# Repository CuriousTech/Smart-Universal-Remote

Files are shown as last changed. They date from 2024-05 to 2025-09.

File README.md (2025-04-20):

# Smart-Universal-Remote  
Smart Universal Remote using one of these:  
[Waveshare ESP32-S3-Touch-LCD-1.28](https://www.waveshare.com/wiki/ESP32-S3-Touch-LCD-1.28)  
[Waveshare ESP32-S3-Touch-LCD-1.69](https://www.waveshare.com/wiki/ESP32-S3-Touch-LCD-1.69)  
[WaveShare-ESP32-S3-Touch-LCD-2.8](https://www.waveshare.com/wiki/ESP32-S3-Touch-LCD-2.8)  
[WaveShare-ESP32-S3-Touch-LCD-2inch](https://www.waveshare.com/wiki/ESP32-S3-Touch-LCD-2)  
  
uremote  
uremote2  
  
This is a tiny smart universal remote with WiFi, IR, capacitive touchscreen, wireless charging (and possibly Bluetooth) all for a very low cost.  
  
Parts list:  
  
[AliExpress ESP32-S3-Touch-1.28](https://www.aliexpress.us/item/3256806026101753.html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) This includes the 12p connector with dupont ends.  
  
[AliExpress ESP32-S3-Touch-1.69](https://www.aliexpress.us/item/3256806781994387.html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)  Or this one. It seems they've fixed the original issue, but I'm not buying another one to test it. [Subreddit thread](https://www.reddit.com/r/esp32/comments/1cxmo5r/esp32s3_169inch_touch_display_features_6axis_imu/)  
  
[AliExpress ESP32-S3-Touch-2.8](https://www.aliexpress.us/item/3256807168316377.html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) My new favorite. Comes with dupont connectors, speakers (not yet implemented). No M2.5 screws, but not hard to find. The wireless charging pad may need to go on the back of the case due to screws.  
  
[eBay:Charger pad](https://www.ebay.com/itm/143351559508?var=442544081497) Select USB-C. These can be bought anywhere.  For the latest model, the charger can be centered. The edges of the pad can be bent because the wrapper is a bit oversized. A USB-C cable or magnetic connector will work as well.  

[eBay:battery](https://www.ebay.com/itm/174781170731?var=473957762104) Select 1.25mm plug. This is probably a decent size. Be careful with the polarity. It was correct on mine. They sell a 1500mAh that's just a little thicker, but I may add a keypad that will use the extra space.   

[TinkerCAD Case Models](https://www.tinkercad.com/things/j1XckJlfVuT-waveshare-esp32-s3-touch-128-remote-case) For editing the 3D print models.  
  
[New IRIO board on OSHPark](https://oshpark.com/shared_projects/KRJOFbjO)  I used some double-sided tape to make sure it doesn't touch the other board.  
  
This IR sender/receiver is designed to be built easily using common parts, but Arduino IR modules should be compatible.  If using an NPN transistor for the sender, subtract the vF from 3.3 for R1 plus the IR LED vF. 110 ohms should be good for a MOSFET and 1.2V LED.  
  
The web page. This is used to decode remotes and test output commands. Just hit the decode button and start pushing buttons on a remote. Those values can be entered in the button code[4] array of any buttons created. Mixed remotes on one page, or all the same. Doesn't matter.  
uremoteweb

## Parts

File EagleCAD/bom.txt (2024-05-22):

RC  TSOP394388
R1  110 ohm 0805
R2  1K 0805
C1  1uF 0805
Q3  N-channel SOT-23 (ex. SSM3K333RLF)
LED1 3mm IR LED (had some laying around)

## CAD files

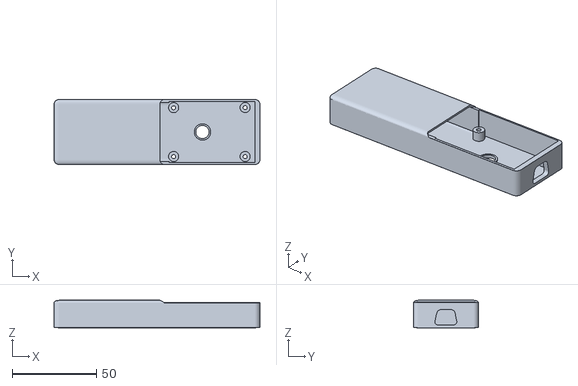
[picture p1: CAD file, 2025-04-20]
3D/WS2inch.stl
122.0 x 38.6 x 16.3

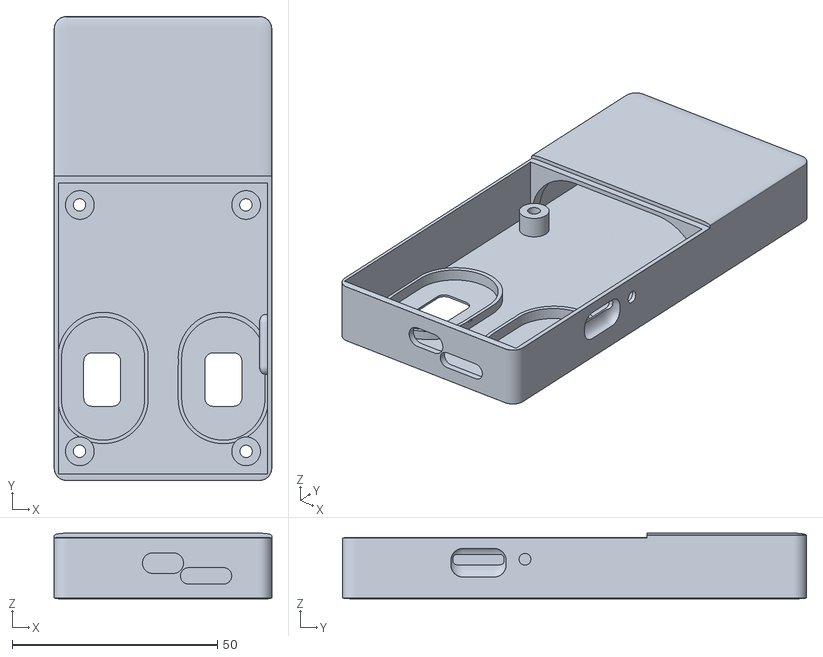
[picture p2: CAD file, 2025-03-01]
3D/WS2.8_Single.stl
53.0 x 113.0 x 16.0

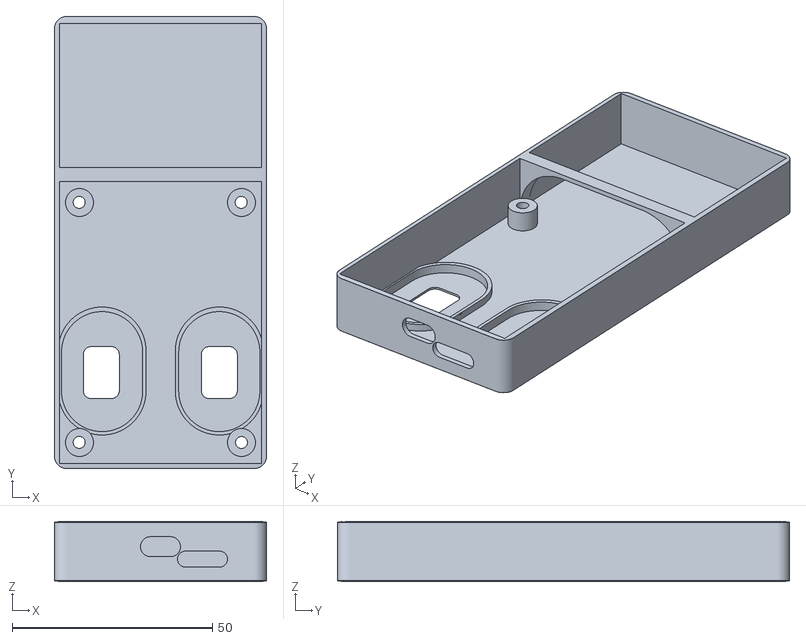
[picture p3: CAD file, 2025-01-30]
3D/WS28Case.stl
53.0 x 113.0 x 15.0

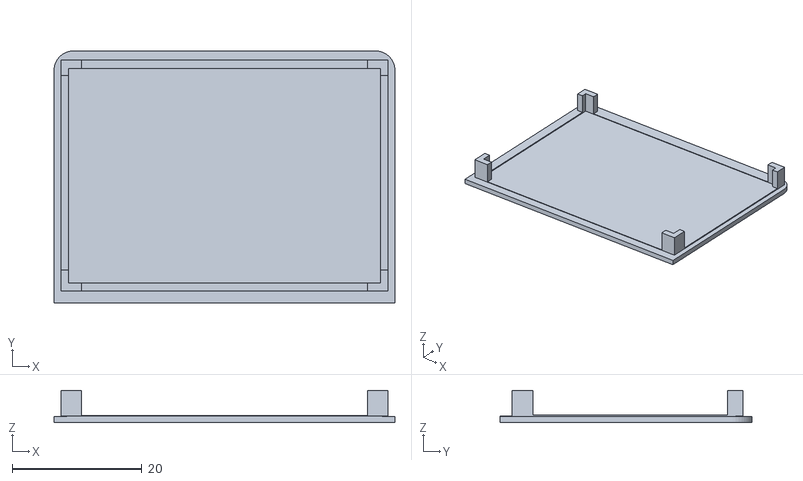
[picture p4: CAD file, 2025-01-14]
3D/WS28Cover.stl
52.5 x 38.8 x 5.00

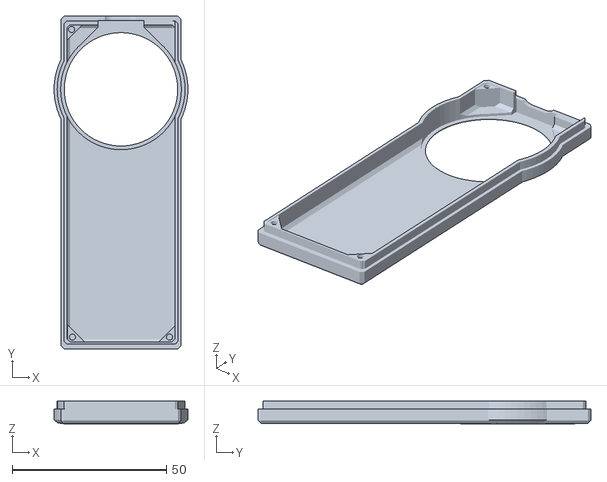
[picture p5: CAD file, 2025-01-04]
3D/URTop.stl
43.5 x 108.0 x 7.36

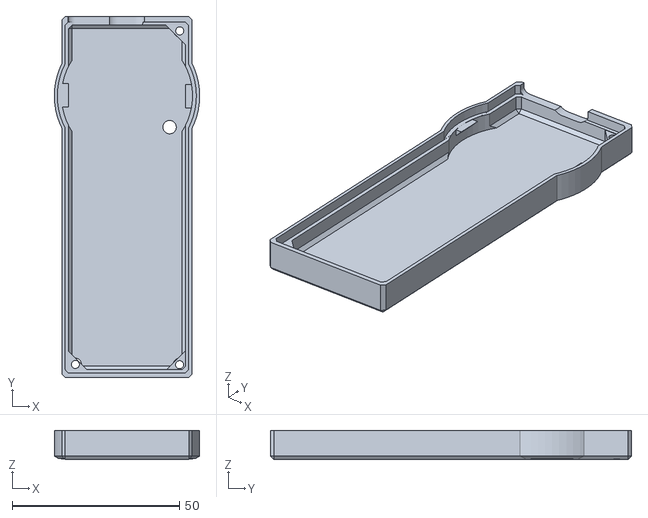
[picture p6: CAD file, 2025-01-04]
3D/URBottom.stl
43.5 x 108.0 x 8.70

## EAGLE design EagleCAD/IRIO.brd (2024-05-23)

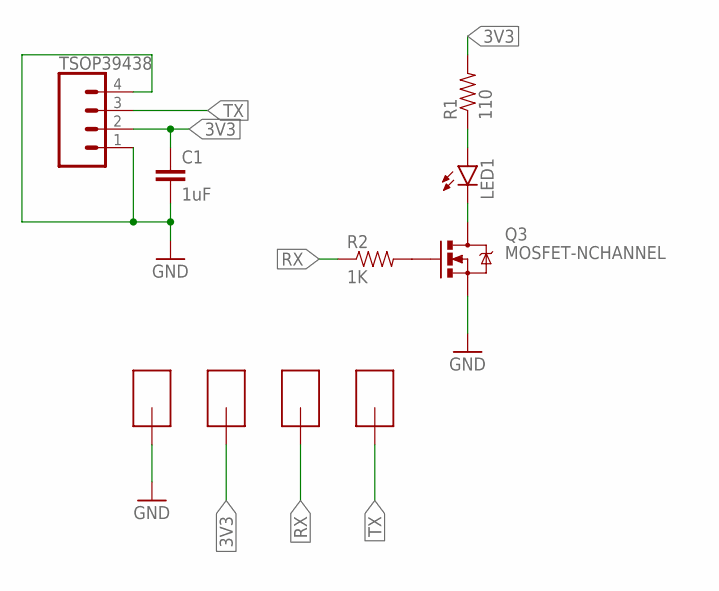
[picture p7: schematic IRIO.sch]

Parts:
C1: 1uF; 0805
LED1: LED5MM
Q3: MOSFET-NCHANNEL; SOT23-3
R1: 110; 0805
R2: 1K; 0805
TSOP39438: CONN_041.27MM; 1X04_1.27MM
U$1, U$2, U$3, U$4: SMD-PAD1SMD-PAD80X32; SMD-PAD6

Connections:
3V3: C1.1, R1.2, TSOP39438.2, U$3.>PAD
GND: C1.2, Q3.2 (S), TSOP39438.1, TSOP39438.4, U$2.>PAD
unnamed: LED1.A, R1.1
unnamed: Q3.1 (G), R2.2
unnamed: LED1.K (C), Q3.3 (D)
RX: R2.1, U$1.>PAD
TX: TSOP39438.3, U$4.>PAD

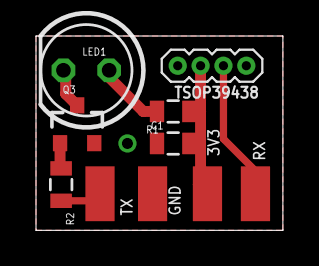
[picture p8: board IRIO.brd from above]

Board: 2 copper layers, 13.7 x 10.8 mm, 10 parts (0 on the bottom side), 7 nets.

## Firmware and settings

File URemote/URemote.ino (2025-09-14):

/**The MIT License (MIT)

Copyright (c) 2024 by Greg Cunningham, CuriousTech

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
THE SOFTWARE IS PROVIDED "AS IS", WITHOUT WARRANTY OF ANY KIND, EXPRESS OR
IMPLIED, INCLUDING BUT NOT LIMITED TO THE WARRANTIES OF MERCHANTABILITY,
FITNESS FOR A PARTICULAR PURPOSE AND NONINFRINGEMENT. IN NO EVENT SHALL THE
AUTHORS OR COPYRIGHT HOLDERS BE LIABLE FOR ANY CLAIM, DAMAGES OR OTHER
LIABILITY, WHETHER IN AN ACTION OF CONTRACT, TORT OR OTHERWISE, ARISING FROM,
OUT OF OR IN CONNECTION WITH THE SOFTWARE OR THE USE OR OTHER DEALINGS IN THE
SOFTWARE.
*/

// Build with Arduino IDE 1.8.57.0
//  ESP32: ( <=2.0.14 or 3.2.0+ ) ESP32S3 Dev Module, QIO, CPU Freq: 80MHz for lowest power (<60mA),
//  Flash: 16MB
//  Partition: 16MB (3MB APP/9.9 FATFS)
// For 1.28" round
//  PSRAM: QSPI PSRAM
//  In TFT_eSPI/User_Setup_Select.h use #include <User_Setups/Setup302_Waveshare_ESP32S3_GC9A01.h>
// For 1.69"
//  PSRAM: OPI PSRAM
//  In TFT_eSPI/User_Setup_Select.h use #include <User_Setups/Setup203_ST7789.h> (custom, included in repo)
// For 2.8"
//  PSRAM: OPI PSRAM
//  In TFT_eSPI/User_Setup_Select.h use #include <User_Setups/Setup303_Waveshare_ESP32S3_ST7789.h> (custom, included in repo)
// For 2"
//  PSRAM: OPI PSRAM
//  In TFT_eSPI/User_Setup_Select.h use #include <User_Setups/Setup304_Waveshare__2inch_ESP32S3_ST7789.h> (custom, included in repo)

#define OTA_ENABLE  //uncomment to enable Arduino IDE Over The Air update code (uses ~4K heap)
#define SERVER_ENABLE // uncomment to enable server and WebSocket
//#define BLE_ENABLE // uncomment for BLE keyboard (uses 510KB (16%) PROGMEN and >100K heap)
#define CLIENT_ENABLE // uncomment for PC WebSocket client
#define IR_ENABLE // uncomment for IR

#include <WiFi.h>
#include "Media.h"
#include "eeMem.h"
#include <time.h>
#include <ESPmDNS.h>
#ifdef OTA_ENABLE
#include <ArduinoOTA.h>
#endif

#ifdef SERVER_ENABLE
#include <ESPAsyncWebServer.h> // https://github.com/mathieucarbou/ESPAsyncWebServer
#include <JsonParse.h> // https://github.com/CuriousTech/ESP-HVAC/tree/master/Libraries/JsonParse
#include "jsonString.h"
#include "pages.h"

#define TZ  "EST5EDT,M3.2.0,M11.1.0"  // https://github.com/nayarsystems/posix_tz_db/blob/master/zones.csv

const char *hostName = "URemote"; // Device and OTA name

tm gLTime;
Media media;

AsyncWebServer server( 80 );
AsyncWebSocket ws("/ws"); // access at ws://[esp ip]/ws
int WsClientID;
void jsonCallback(int16_t iName, int iValue, char *psValue);
JsonParse jsonParse(jsonCallback);
#endif
int WsPcClientID;

#ifdef BLE_ENABLE
#include <BleKeyboard.h> // https://github.com/T-vK/ESP32-BLE-Keyboard
BleKeyboard bleKeyboard;
#endif

#ifdef CLIENT_ENABLE
#include "WebSocketClient.h"
WebSocketClient WsClient;
bool bWscConnected;
void WscSend(String s);
void startListener(void);
#endif

#ifdef IR_ENABLE
#if (USER_SETUP_ID==302) // 240x240
 #define IR_RECEIVE_PIN   15
 #define IR_SEND_PIN      16
#else
 #define IR_RECEIVE_PIN   44 // UART0
 #define IR_SEND_PIN      43
#endif

//#define DISABLE_CODE_FOR_RECEIVER // Disables restarting receiver after each send. Saves 450 bytes program memory and 269 bytes RAM if receiving functions are not used.
#define EXCLUDE_EXOTIC_PROTOCOLS  // Saves around 240 bytes program memory if IrSender.write is used
//#define SEND_PWM_BY_TIMER         // Disable carrier PWM generation in software and use (restricted) hardware PWM.
//#define USE_NO_SEND_PWM           // Use no carrier PWM, just simulate an active low receiver signal. Overrides SEND_PWM_BY_TIMER definition
#define NO_LED_FEEDBACK_CODE      // Saves 566 bytes program memory

#if !defined(RAW_BUFFER_LENGTH)
#  if RAMEND <= 0x4FF || RAMSIZE < 0x4FF
#define RAW_BUFFER_LENGTH  180  // 750 (600 if we have only 2k RAM) is the value for air condition remotes. Default is 112 if DECODE_MAGIQUEST is enabled, otherwise 100.
#  elif RAMEND <= 0x8FF || RAMSIZE < 0x8FF
#define RAW_BUFFER_LENGTH  600  // 750 (600 if we have only 2k RAM) is the value for air condition remotes. Default is 112 if DECODE_MAGIQUEST is enabled, otherwise 100.
#  else
#define RAW_BUFFER_LENGTH  750  // 750 (600 if we have only 2k RAM) is the value for air condition remotes. Default is 112 if DECODE_MAGIQUEST is enabled, otherwise 100.
#  endif
#endif
#define MARK_EXCESS_MICROS    20    // Adapt it to your IR receiver module. 20 is recommended for the cheap VS1838 modules.

#include <IRremote.hpp> // IRremote from library manager
#endif

#include "display.h"
#include "Lights.h" // Uses ~3KB
Lights lights;

bool bConfigDone = false; // EspTouch done or creds set
bool bStarted = false; // first start
bool bRestarted = false; // consecutive restarts
bool bRXActive;

Display display;
eeMem ee;

void WsSend(String s)
{
  ws.textAll(s);
}

void consolePrint(String s)
{
#ifdef SERVER_ENABLE
  jsonString js("print");
  js.Var("text", s);
  ws.textAll(js.Close());
#endif
}

#if defined(SERVER_ENABLE) && !defined(DISABLE_CODE_FOR_RECEIVER)
void decodePrint(uint8_t proto, uint16_t addr, uint16_t cmd, uint32_t raw, uint8_t bits, uint8_t flags)
{
  jsonString js("decode");
  js.Var("proto", proto);
  js.Var("addr", addr);
  js.Var("code", cmd);
  js.Var("raw", raw);
  js.Var("bits", bits);
//  js.Var("flags", flags);

  String s = js.Close();
  ws.textAll(s);
}
#endif

void sendIR(uint16_t *pCode)
{
#ifdef IR_ENABLE
  display.RingIndicator(0);
  IRData IRSendData;
  IRSendData.protocol = (decode_type_t)pCode[0];
  IRSendData.address = pCode[1]; // Address
  IRSendData.command = pCode[2]; // Command
  IRSendData.flags = IRDATA_FLAGS_EMPTY;

  IrSender.write(&IRSendData, pCode[3]); // 3=repeats
//    delay(DELAY_AFTER_SEND);

#ifdef SERVER_ENABLE
  jsonString js("send");
  js.Var("proto", pCode[0]);
  js.Var("addr", pCode[1]);
  js.Var("code", pCode[2]);
  js.Var("rep", pCode[3]);
  ws.textAll(js.Close());  
#endif
#endif
}

//-----------------

void stopWiFi()
{
  if(WiFi.status() != WL_CONNECTED)
    return;

//  ets_printf("stopWifi\n");
  ee.update();
#ifdef OTA_ENABLE
  ArduinoOTA.end();
  delay(100); // fix ArduinoOTA crash
#endif

  display.m_nWsConnected = 0;
#ifdef SERVER_ENABLE
  WsClientID = 0;
  WsPcClientID = 0;
#endif

  WiFi.setSleep(true);
  bRestarted = false;
}

const char *szWiFiStat[] = {
    "IDLE", "NO_SSID_AVAIL", "SCAN_COMPLETED", "CONNECTED", "CONNECT_FAILED", "CONNECTION_LOST", "DISCONNECTED"
};

bool secondsWiFi() // called once per second
{
  bool bConn = false;

  if(display.m_bSleeping)
    return false;

//  ets_printf("wifi status = %s\n", szWiFiStat[WiFi.status()]); // Wifi debugging

  if(!bConfigDone)
  {
    if( WiFi.smartConfigDone())
    {
      bConfigDone = true;
      WiFi.SSID().toCharArray(ee.szSSID, sizeof(ee.szSSID)); // Get the SSID from SmartConfig or last used
      WiFi.psk().toCharArray(ee.szSSIDPassword, sizeof(ee.szSSIDPassword) );
    }
  }
  if(bConfigDone)
  {
    if(WiFi.status() == WL_CONNECTED)
    {
      if(!bStarted)
      {
        MDNS.begin( hostName );
        bStarted = true;
        MDNS.addService("iot", "tcp", 80);
        configTime(0, 0, "pool.ntp.org");
        setenv("TZ", TZ, 1);
        tzset();
        lights.init();
        bConn = true;
#ifdef CLIENT_ENABLE
        startListener();
#endif
      }
      if(!bRestarted) // wakeup work if needed
      {
        bRestarted = true;
// todo: reconnect to host
      }
    }
    else if(WiFi.status() == WL_CONNECT_FAILED) // failed to connect for some reason
    {
      WiFi.mode(WIFI_AP_STA);
      WiFi.beginSmartConfig();
      bConfigDone = false;
      bStarted = false;
    }
  }

  return bConn;
}

bool sendBLE(uint16_t *pCode)
{
#ifdef BLE_ENABLE
  return bleKeyboard.write(pCode[0]);
#else
  return false;
#endif
}

bool sendPCMediaCmd( uint16_t *pCode)
{
#ifdef CLIENT_ENABLE

  display.RingIndicator(2);
  if(pCode[0] == 1000)
  {
    jsonString js("volume");
    js.Var("value", pCode[1]);
    WscSend(js.Close());
  }
  else if(pCode[0] == 1001)
  {
    jsonString js("pos");
    js.Var("value", pCode[1]);
    WscSend(js.Close());
  }
  else
  {
    jsonString js("media");
    js.Var("HOTKEY", pCode[0]);
    WscSend(js.Close());
  }
  return true;
#else
  return false;
#endif
}

// Currently using PC to relay
bool sendStatCmd( uint16_t *pCode)
{
#ifdef CLIENT_ENABLE
  display.RingIndicator(2);
  jsonString js("STAT");
  js.Var("value", pCode[0]);
  WscSend(js.Close());
  return true;
#else
  return false;
#endif
}

// Currently using PC to relay
bool sendGdoCmd( uint16_t *pCode)
{
#ifdef CLIENT_ENABLE
  display.RingIndicator(2);
  jsonString js("GDOCMD");
  js.Var("value", pCode[0]);
  WscSend(js.Close());
  return true;
#else
  return false;
#endif
}

#ifdef SERVER_ENABLE

const char *jsonListCmd[] = {
  "PROTO", // IR send commands
  "ADDR",
  "CODE",
  "REP",
  "RX",
  "PC_REMOTE", // PC commands client
  "PC_VOLUME",
  "PC_MED_POS",
  "LED",
  "STATTEMP",
  "STATSETTEMP", // 10
  "STATFAN",
  "OUTTEMP",
  "ST", // sleeptime
  "SS", // screensaver time
  "restart",
  "GDODOOR",
  "GDOCAR",
  "setfs",
  "cd",
  "delf", // 20
  "createdir",
  NULL
};

// this is for the web page, and needs to be seperated from the PC client
void jsonCallback(int16_t iName, int iValue, char *psValue)
{
  static uint16_t code[4];

  switch (iName)
  {
    case 0: // PROTO
      code[0] = iValue;
      break;
    case 1: // ADDR
      code[1] = iValue;
      break;
    case 2: // CODE
      code[2] = iValue;
      break;
    case 3: // REP
      code[3] = iValue;
      sendIR(code);
      break;
    case 4: // RX
#if defined(IR_ENABLE) && !defined(DISABLE_CODE_FOR_RECEIVER)
      IrReceiver.begin(IR_RECEIVE_PIN);
      consolePrint("Decode started");
      bRXActive = true;
#endif
      break;
    case 5: // PC_REMOTE
      if(WsPcClientID == 0)
        WsPcClientID = WsClientID;
      break;
    case 6: // PC_VOLUME
      display.setSliderValue(BTF_PCVolume, iValue);
      break;
    case 7: // PC_MED_POS
      display.setSliderValue(BTF_PC_Media, iValue);
      break;
    case 8: // LED
//      digitalWrite(IR_SEND_PIN, iValue ? HIGH:LOW);
      break;
    case 9: // STATTEMP
      display.m_statTemp = iValue;
      break;
    case 10: // STATSETTEMP
      display.m_statSetTemp = iValue;
      break;
    case 11: // STATFAN
      display.m_bStatFan = iValue;
      break;
    case 12: // OUTTEMP
      display.m_outTemp = iValue;
      break;
    case 13: // ST
      ee.sleepTime = iValue;
      break;
    case 14: // SS
      ee.ssTime = iValue;
      break;
    case 15:
      ESP.restart();
      break;
    case 16:
      display.m_bGdoDoor = iValue;
      break;
    case 17:
      display.m_bGdoCar = iValue;
      break;
    case 18: // setfs
      media.setFS(psValue);
      ws.textAll(setupJson()); // update FS and disk free
      break;
    case 19: // cd
      media.setPath(psValue);
      break;
    case 20: // delf
      media.deleteFile(psValue);
      ws.textAll(setupJson()); // update disk free
      break;
    case 21: // createdir
      media.createDir(psValue);
      ws.textAll(setupJson()); // update disk free
      break;
  }
}

#endif

void startWiFi()
{
  if(WiFi.status() == WL_CONNECTED)
    return;

  WiFi.setSleep(false);

  WiFi.hostname(hostName);
  WiFi.mode(WIFI_STA);

  if ( ee.szSSID[0] )
  {
    WiFi.begin(ee.szSSID, ee.szSSIDPassword);
    WiFi.setHostname(hostName);
    bConfigDone = true;
//    ets_printf("Start WiFi %s %s\n", ee.szSSID, ee.szSSIDPassword);
  }
  else
  {
    WiFi.beginSmartConfig();
    display.notify("Use EspTouch");
  }

#ifdef OTA_ENABLE
  ArduinoOTA.setHostname(hostName);
  ArduinoOTA.begin();
  ArduinoOTA.onStart([]() {
    display.notify("OTA Update");
    ee.update();
#ifdef SERVER_ENABLE
    jsonString js("print");
    js.Var("text", "OTA update started");
    ws.textAll(js.Close());
#endif
    delay(100);
  });
#endif

#ifdef SERVER_ENABLE
  static bool bInit = false;
  if(!bInit)
  {
    bInit = true;
    ws.onEvent(onWsEvent);
    server.addHandler(&ws);
  
    server.on ( "/", HTTP_GET | HTTP_POST, [](AsyncWebServerRequest * request)
    {
      request->send_P( 200, "text/html", page1);
    });

    server.on ( "/fm.html", HTTP_GET | HTTP_POST, [](AsyncWebServerRequest * request)
    {
      request->send_P( 200, "text/html", fileman);
    });

    server.onNotFound([](AsyncWebServerRequest * request) {
      request->send(404);
    });
    server.on("/heap", HTTP_GET, [](AsyncWebServerRequest * request) {
      request->send(200, "text/plain", String(ESP.getFreeHeap()));
    });
  
    server.on("/favicon.ico", HTTP_GET, [](AsyncWebServerRequest * request) {
      AsyncWebServerResponse *response = request->beginResponse_P(200, "image/x-icon", favicon, sizeof(favicon));
      response->addHeader("Content-Encoding", "gzip");
      request->send(response);
    });
    server.on("/del-btn.png", HTTP_GET, [](AsyncWebServerRequest *request){
      AsyncWebServerResponse *response = request->beginResponse_P(200, "image/png", delbtn_png, sizeof(delbtn_png));
      request->send(response);
    });
    server.on ( "/upload", HTTP_POST, [](AsyncWebServerRequest * request)
    {
      request->send( 200);
      ws.textAll(setupJson()); // update free space
    },
    [](AsyncWebServerRequest *request, String filename, size_t index, uint8_t *data, size_t len, bool final)
     {
      if(!index)
        request->_tempFile = media.createFile(filename);
      if(len)
       request->_tempFile.write((byte*)data, len);
      if(final)
        request->_tempFile.close();
     }
    );

    server.serveStatic("/", INTERNAL_FS, "/");
    server.begin();
    jsonParse.setList(jsonListCmd);
  }
#endif
}

void serviceWiFi()
{
#ifdef OTA_ENABLE
// Handle OTA server.
  ArduinoOTA.handle();
#endif
}

#ifdef SERVER_ENABLE

//this does basically nothing for now (but used for keepalive)
String dataJson()
{
  jsonString js("state");
  js.Var("t", (long)time(nullptr) );
  return js.Close();
}

uint8_t ssCnt = 26;

void sendState()
{
  if (display.m_nWsConnected)
    ws.textAll( dataJson() );
  ssCnt = 58;
}

String setupJson()
{
  jsonString js("settings");
  js.Var("st", ee.sleepTime);
  js.Var("ss", ee.ssTime);
  js.Var("diskfree",  media.freeSpace() );
  js.Var("sdavail",  media.SDCardAvailable() );
  js.Var("currfs", media.currFS());
  js.Var("vmax", ee.vadcMax);
  return js.Close();
}

void onWsEvent(AsyncWebSocket * server, AsyncWebSocketClient * client, AwsEventType type, void * arg, uint8_t *data, size_t len)
{ //Handle WebSocket event

  switch (type)
  {
    case WS_EVT_CONNECT:      //client connected
      client->text(setupJson());
      client->text(dataJson());
      display.m_nWsConnected++;
      WsClientID = client->id();
      media.setPath("/"); // trigger file list send
      break;
    case WS_EVT_DISCONNECT:    //client disconnected
      if (display.m_nWsConnected)
        display.m_nWsConnected--;
      WsClientID = 0;
      if(client->id() == WsPcClientID)
        WsPcClientID = 0;
      break;
    case WS_EVT_ERROR:    //error was received from the other end
      break;
    case WS_EVT_PONG:    //pong message was received (in response to a ping request maybe)
      break;
    case WS_EVT_DATA:  //data packet
      AwsFrameInfo * info = (AwsFrameInfo*)arg;
      if (info->final && info->index == 0 && info->len == len) {
        //the whole message is in a single frame and we got all of it's data
        if (info->opcode == WS_TEXT) {
          data[len] = 0;
          jsonParse.process((char *)data);
        }
      }
      break;
  }
}
#endif

void setup()
{
//  delay(1000);
//  ets_printf("\nStarting\n"); // print over USB (if using UART pins for IR, don't print after it starts)
//  ets_printf("Free: %ld\n", heap_caps_get_free_size(MALLOC_CAP_8BIT) );

  media.init();
  ee.init();
  display.init();

  if(ee.bWiFiEnabled)
    startWiFi();

#ifdef IR_ENABLE
  pinMode(IR_SEND_PIN, OUTPUT);
  digitalWrite(IR_SEND_PIN, LOW);
  IrSender.begin(); // Start with IR_SEND_PIN as send pin
  IrSender.enableIROut(SAMSUNG_KHZ); // Call it with 38 kHz just to initialize the values

#endif

  if(ee.bBtEnabled == false)
    btStop();
#ifdef BLE_ENABLE
  if(ee.bBtEnabled)
    bleKeyboard.begin();
#endif
}

void loop()
{
  static uint8_t hour_save, min_save = 255, sec_save;
  static int8_t lastSec;
  static int8_t lastHour;

  display.service();  // check for touch, etc.
  media.service();

  serviceWiFi(); // handles OTA

#if defined(IR_ENABLE) && !defined(DISABLE_CODE_FOR_RECEIVER)
  if(bRXActive)
  {
     if (IrReceiver.decode())
     {
        if (IrReceiver.decodedIRData.flags & IRDATA_FLAGS_WAS_OVERFLOW)
        {
//          consolePrint("Try to increase the \"RAW_BUFFER_LENGTH\" value" );
        }
        else
        {
            if (IrReceiver.decodedIRData.protocol == UNKNOWN)
            {
              consolePrint(F("Received noise or an unknown (or not yet enabled) protocol. Stopped"));

              ets_printf("Received noise or an unknown (or not yet enabled) protocol. Stopped\r\n");

              IrReceiver.stop();
              bRXActive = false;
            }
            else
            {
              display.RingIndicator(1);
#ifdef SERVER_ENABLE
              decodePrint( IrReceiver.decodedIRData.protocol, IrReceiver.decodedIRData.address, IrReceiver.decodedIRData.command,
                IrReceiver.decodedIRData.decodedRawData, IrReceiver.decodedIRData.numberOfBits, IrReceiver.decodedIRData.flags);
#endif
              IrReceiver.resume();
            }
        }
     }
  }
#endif

  static uint32_t lastMS;
  if(millis() - lastMS >= 1000) // only do stuff once per second
  {
    lastMS = millis();
    getLocalTime(&gLTime);

    secondsWiFi(); // once per second stuff, returns true once on connect

    display.oneSec();

    if(min_save != gLTime.tm_min) // only do stuff once per minute
    {
      min_save = gLTime.tm_min;

      if(hour_save != gLTime.tm_hour) // update our IP and time daily (at 2AM for DST)
      {
        hour_save = gLTime.tm_hour;
        if(hour_save == 2 && WiFi.status() == WL_CONNECTED)
        {
          configTime(0, 0, "pool.ntp.org");
          setenv("TZ", TZ, 1);
          tzset();
        }
        ee.update();
      }
    }
#ifdef SERVER_ENABLE
    if (--ssCnt == 0) // keepalive
      sendState();
#endif
  }

  delay(1);
}

// remote WebSocket for sending all commands to PC and recieving states
// Thermostate and GDO go through this as well for speed

#ifdef CLIENT_ENABLE

void WscSend(String s) 
{
  if(bWscConnected)
    WsClient.send(s);
}

void webSocketEventHandler(uint8_t event, char *data, uint16_t length)
{
  switch(event)
  {
    case WEBSOCKET_EVENT_ERROR:
      break;
    case WEBSOCKET_EVENT_CONNECTED:
      bWscConnected = true;
//      display.notify("PC connected"); // helps see things connecting
      break;
    case WEBSOCKET_EVENT_DISCONNECTED:
      bWscConnected = false;
      break;
    case WEBSOCKET_EVENT_DATA_TEXT:
      jsonParse.process(data);
      break;
    case WEBSOCKET_EVENT_DATA_BINARY:
      break;
  }
}

void startListener()
{
  IPAddress ip(ee.hostIp);
  WsClient.connect((char *)ip.toString().c_str(), "/ws", ee.hostPort);
  WsClient.setCallback(webSocketEventHandler);
}
#endif

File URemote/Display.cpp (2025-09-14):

/*
Display and UI code
*/

#include <WiFi.h>
#include <time.h>
#include "eeMem.h"
#include "CST816T.h"
#include "Lights.h"
#include <FunctionalInterrupt.h>
#include "display.h"
#include <math.h>
#include "QMI8658.h"
#include "Media.h"

TFT_eSPI tft = TFT_eSPI();
TFT_eSprite sprite = TFT_eSprite(&tft);

//Lights class
extern Lights lights;

// URemote functions
extern int WsPcClientID;
extern tm gLTime;
extern void stopWiFi();
extern void startWiFi();
extern void sendIR(uint16_t *pCode);
extern bool sendBLE(uint16_t *pCode);
extern bool sendPCMediaCmd( uint16_t *pCode);
extern bool sendStatCmd( uint16_t *pCode);
extern bool sendGdoCmd( uint16_t *pCode);
extern void consolePrint(String s); // for browser debug

#if (USER_SETUP_ID==302) // 240x240

 #define I2C_SDA   6
 #define I2C_SCL   7
 #define IMU_INT   3 // INT2
 #define TP_RST   13
 #define TP_INT    GPIO_NUM_5 // normally high
 #define TFT_BL    2
 #define BATTV     1

 #define DISPLAY_HEIGHT 240
 CST816T touch(I2C_SDA, I2C_SCL, TP_RST, TP_INT);
#endif

#if (USER_SETUP_ID==303) // 240x320 2.8"
 #define I2C_SDA  11
 #define I2C_SCL  10
 #define TP_SDA    1
 #define TP_SCL    3
 #define IMU_INT  12 // INT2
 #define TP_RST    2
 #define TP_INT    GPIO_NUM_4 // normally high
 #define TFT_BL    5
 #define BATTV     8
 #define PWR_CTRL  7
 #define PWR_BTN   6
 
 #define DISPLAY_HEIGHT 320
 #include "CST328.h"
 CST328 touch(TP_SDA, TP_SCL, TP_RST, TP_INT);
#endif

#if (USER_SETUP_ID==203) // 240x280
 #define I2C_SDA  11
 #define I2C_SCL  10
 #define IMU_INT  38 // INT1
 #define TP_RST   13
 #define TP_INT   GPIO_NUM_14 // normally high
 #define TFT_BL   15
 #define BATTV     1

 #define DISPLAY_HEIGHT 280
 CST816T touch(I2C_SDA, I2C_SCL, TP_RST, TP_INT);
#endif

#if (USER_SETUP_ID==304) // 240x320 2"
 #define I2C_SDA  48
 #define I2C_SCL  47
 #define TP_SDA   48
 #define TP_SCL   47
 #define IMU_INT   3 // INT1
 #define TP_RST   -1
 #define TP_INT    GPIO_NUM_46 // normally high
 #define TFT_BL    1
 #define BATTV     5
 
 #define DISPLAY_HEIGHT 320
 CST816T touch(TP_SDA, TP_SCL, TP_RST, TP_INT);
#endif

const int16_t bgColor = TFT_BLACK;

QMI8658 qmi;

#include "screensavers.h" // comment this line to remove screensavers (saves 3172b PROGMEM, 1072b SRAM)
#ifdef SCREENSAVERS_H
ScreenSavers ss;
#endif

#define ROTATE_DISPLAY // Upside down, puts USB on top
#define TITLE_HEIGHT 40
#define BORDER_SPACE 3 // H and V spacing + font size for buttons and space between buttons

void Display::init(void)
{
  pinMode(TFT_BL, OUTPUT);

  ee.bBtEnabled = false; // BUG

#ifdef PWR_CTRL // Power stay-on thing
  pinMode(PWR_CTRL, OUTPUT);
  digitalWrite(PWR_CTRL, HIGH);
#endif

  tft.init();
#ifdef ROTATE_DISPLAY
  tft.setRotation(2);
#endif
  tft.setTextPadding(8); 

#if (USER_SETUP_ID==302) // 240x240
  tft.setSwapBytes(true);
  sprite.setSwapBytes(true);
#endif

  sprite.createSprite(DISPLAY_WIDTH, DISPLAY_HEIGHT); // This uses over 115K RAM for 240x240
  
  drawTile(m_nCurrTile, true, 0, 0);
  sprite.pushSprite(0, 0); // draw screen 0 on start

  // count tiles, index rows, count columns, format the buttons
  uint8_t nRowIdx = 0;

  for(m_nTileCnt = 0; m_nTileCnt < TILES && (m_tile[m_nTileCnt].Extras || m_tile[m_nTileCnt].pszTitle || m_tile[m_nTileCnt].pBGImage); m_nTileCnt++) // count screens
  {
    if(m_tile[m_nTileCnt].nRow != nRowIdx)
      m_nRowStart[++nRowIdx] = m_nTileCnt;
    m_nColCnt[nRowIdx]++;
    formatButtons(m_tile[m_nTileCnt]);
  }

  pinMode(IMU_INT, INPUT);
  qmi.init(I2C_SDA, I2C_SCL);
  touch.begin();
  attachInterrupt(IMU_INT, std::bind(&Display::handleISR, this), RISING);

  qmi.setWakeOnMotion(true); // set WOM (sets acc values)
  m_intTriggered = false;
#ifdef SCREENSAVERS_H
  randomSeed(micros());
  ss.init(DISPLAY_WIDTH, DISPLAY_HEIGHT);
#endif
}

void Display::exitScreensaver()
{
  m_backlightTimer = ee.ssTime; // reset timer for any touch

  if( m_brightness == ee.brightLevel[0] ) // screensaver active
  {
    drawTile(m_nCurrTile, true, 0, 0); // draw over screensaver
    sprite.pushSprite(0, 0);
    qmi.setWakeOnMotion(false); // enable gyro/acc/temp
    m_intTriggered = false; // causes an interrupt
  }
  m_brightness = ee.brightLevel[1]; // increase brightness for any touch
}

void Display::service(void)
{
  if( m_intTriggered) // set for IMU WOM
  {
    m_intTriggered = false;
    m_backlightTimer = ee.ssTime;
    if( m_brightness < ee.brightLevel[1] )
      exitScreensaver();
  }

  if(m_bSleeping)
  {
    if( snooze(30000) )
    {
      endSleep();
      m_backlightTimer = ee.ssTime;
    }
    else
      return;
  }

  dimmer();

  if(m_nDispFreeze)
  {
    if( millis() < m_nDispFreeze) // freeze display for notification
      return;
    m_nDispFreeze = 0;
  }

  battRead();

#ifdef SCREENSAVERS_H
  if(m_brightness == ee.brightLevel[0]) // full dim activates screensaver
    ss.run();
#endif

  static bool bScrolling; // scrolling active
  static bool bSliderHit;
  static int16_t touchXstart, touchYstart; // first touch pos for scolling and non-moving detect
  static uint32_t touchStartMS; // timing for detecting swipe vs press

  if(touch.available() )
  {
#ifdef ROTATE_DISPLAY
    touch.x = DISPLAY_WIDTH - touch.x;
    touch.y = DISPLAY_HEIGHT - touch.y;
#endif
    if(touch.event == 0) // initial touch
    {
      touchXstart = touch.x;
      touchYstart = touch.y;
      touch.gestureID = 0;
      bSliderHit = false;
      bScrolling = false;
      touchStartMS = millis();

      m_backlightTimer = ee.ssTime; // reset timer for any touch
  
      if( m_brightness < ee.brightLevel[1] )
      {
        exitScreensaver();
        endSleep();
      }
    }
    else if(touch.event == 1) // release
    {
      if(m_pCurrBtn)
      {
        drawButton(m_tile[m_nCurrTile], m_pCurrBtn, false, 0, 0, false); // draw released button
        sprite.pushSprite(0, 0);

        if(m_pCurrBtn && (m_pCurrBtn->flags & (BF_SLIDER_H|BF_SLIDER_V)) )
        {
          buttonCmd(m_pCurrBtn, true);
        }

        m_pCurrBtn = NULL;
      }
      else if(touch.gestureID)
      {
        snapTile(); // finish the swipe (only forward for now)
        m_bSwipeReady = false;
        touch.gestureID = 0; // unlock the idle display updates
      }
      else if(bScrolling == false) // check for a quick button hit if nothing else appeared to happen
      {
        checkButtonHit(touchXstart, touchYstart);
      }
      touch.gestureID = 0;
    }
    else // 2=active
    {
      if( m_brightness < ee.brightLevel[1] ) // ignore input until brightness is full
        return;

      Tile& pTile = m_tile[m_nCurrTile];
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

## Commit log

2024-02-29 Abandoning the ESP32C3-MINI version
2024-02-29 Abandoning the ESP32C3 model
2024-03-06 Gave up on battery monitor
2024-03-08 1mm taller for better IRIO fitment
    [URCase.stl, URCover.stl]
2024-03-28 Delete 3D/URButton.stl
    New model, no button
    [URButton.stl]
2024-03-28 Waveshare model case
    [URBack.stl, URCase.stl]
2024-03-28 Updated for the Waveshare display board
2024-03-28 Added charging detect
2024-04-01 A bit tighter
    [URBack.stl, URCase.stl]
2024-04-04 Accelerometer testing moslty
2024-04-05 Removed calls to draw inside callback (unstable)
    [URemote.ino]
2024-04-09 Added battery meter
2024-05-05 Switched to WebSocket client
2024-05-05 Brightness slider, volt avg
2024-05-05 Newer design
    [URBottom.stl, URTop.stl]
2024-05-22 Slimmer design with TSOP39438
    [IRIO.brd, IRIO.sch]
2024-05-22 Switched from EEPROM to fat file
2024-05-22 Added snap-back on swipe
    [Display.cpp]
2024-05-23 Corrected footprint for TSOP39438
    [IRIO.brd, IRIO.sch]
2024-05-27 external pin defs
2024-05-30 Removed problematic 1.69" features
    [URemote.ino]
2024-05-30 Removed problematic 1.69" code
    [Display.cpp]
2024-06-20 Non-round battery meter
2024-06-30 Removed button.ID
2025-01-04 Flipped for easy USB access
    [URBottom.stl, URTop.stl]
2025-01-04 added ROTATE_DISPLAY for new flipped case
    [Display.cpp]
2025-01-14 Case for WaveShare ESP32S3 2.8
    [WS28Case.stl, WS28Cover.stl]
2025-01-14 Added batt max value calibration
2025-01-14 TFT_eSPI Setup file for WaveShare-ESP32-Touch-2.8
2025-01-21 Replaced arrow images with drawn
    [Display.cpp]
2025-01-26 A few issues found with the 2.8"
    [Display.cpp]
2025-01-30 Add files via upload
    Betterer
    [WS28Case.stl]
2025-01-30 TP_INT for 2.8" fix, added rect for buttons
    [Display.cpp]
2025-01-30 Added rect for buttons, cleaner
2025-02-27 Drag/drop file upload, dload, delete button
2025-03-01 Single part case for 2.8"
    [WS2.8_Single.stl]
2025-03-10 Added power off button
2025-04-17 Pin setup for 2"
2025-04-17 SD card for 2" (SPI)
2025-04-17 Pin setup for 2" SPI SD
2025-09-14 using esp32 time lib
2025-09-14 battery % stuff

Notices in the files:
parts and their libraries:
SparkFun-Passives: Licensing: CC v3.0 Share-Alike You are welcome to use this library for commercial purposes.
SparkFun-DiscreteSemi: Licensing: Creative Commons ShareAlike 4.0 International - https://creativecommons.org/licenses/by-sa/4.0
